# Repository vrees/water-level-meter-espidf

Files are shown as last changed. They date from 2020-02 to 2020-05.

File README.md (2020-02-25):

# water-level-meter
Measure the water level in Viktor's spring tank using ESP32 espidf Framework

### Links:
* Board: https://github.com/LilyGO/TTGO-LORA32
* https://github.com/manuelbl/ttn-esp32
* https://github.com/bertrik/LoraWanPmSensor/blob/master/Esp32PmSensor/Esp32PmSensor.ino
* Display Library u8g2: https://github.com/olikraus/u8g2/wiki

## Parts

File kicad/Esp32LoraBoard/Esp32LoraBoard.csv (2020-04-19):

Source | /home/vrees/work/git-repos/water-level-meter-espidf/kicad/Esp32LoraBoard/Esp32LoraBoard.sch
Kicad Rev | Eeschema 5.1.4-e60b266~84~ubuntu18.04.1
Generated Date | Sa 18 Apr 2020 08:45:09 CEST
Title | Esp32LoraBoard
Company | Viktor Rees
Revision | 1.1
Date Issue | 2020-04-11
Comment | Reset-Button added
Reference | Value | Feld4 | Feld5 | Feld6 | Feld7 | Description | Height | Manufacturer_Name | Manufacturer_Part_Number | Library | Library Ref
U3 | RFM95W-868S2 | RF_Module | RFM95W-868S2
J1 | USB_B_Micro | Connector | USB_B_Micro
C1 | 100n | Device | C
C2 | 10u | Device | CP_Small
R1 | 10k | Device | R
C4 | 100n | Device | C_Small
C3 | 1u | Device | C_Small
AE1 | Antenna_Shield | Device | Antenna_Shield
BT1 | LiFePo-Batterie | Device | Battery_Cell
U1 | LM3940IMP-3.3 | 41K5122 | LM3940IMP-33 | SOT-223-4 | National Semiconductors |  |  |  |  | LM3940IMP-3.3 | LM3940IMP-3.3
J2 | Power-Selector | Connector | Conn_01x03_Male
J4 | ESP_PROG_JTAG | Connector_Generic | Conn_02x05_Odd_Even
C5 | 1n | Device | C_Small
R2 | 10k | Device | R
C6 | 1n | Device | C_Small
Q1 | UMH3N |  |  |  |  | 2 NPN pre-biased (Dual) 100mA 50V SC-70-6(SOT-363) Digital Transistors RoHS | 1.1 | Changjiang Electronics Tech (CJ) | UMH3N | UMH3N | UMH3N
J5 | Prog | Connector | Conn_01x05_Male
U2 | ESP32-WROOM-32 | RF_Module | ESP32-WROOM-32
Q2 | Si2302DS_NMOS | Device | Q_NMOS_GSD
R5 | optional | Device | R
R6 | optional | Device | R
R7 | 100k | Device | R
J7 | Measurement-Selector | Connector | Conn_01x03_Male
R8 | 100k | Device | R
TP1 | TP_U_BATT | Connector | TestPoint
R4 | 10k | Device | R
R3 | 10k | Device | R
J6 | ext_Measure | Connector | Screw_Terminal_01x04
J3 | Testpoints | Connector | Conn_01x05_Male
Q3 | Si2301DS_PMOS | Device | Q_PMOS_GSD
TP3 | VCC_2 | Connector | TestPoint
Q5 | Si2301DS_PMOS | Device | Q_PMOS_GSD
R12 | 100k | Device | R
R13 | 10k | Device | R
R11 | 10k | Device | R
Q6 | Si2302DS_NMOS | Device | Q_NMOS_GSD
J8 | OLED_128x64 | Connector | Conn_01x04_Female
R10 | 10k | Device | R
R9 | 10k | Device | R
Q4 | Si2302DS_NMOS | Device | Q_NMOS_GSD
TP2 | TP_U_EXT | Connector | TestPoint
C8 | 100n | Device | C
C7 | 100n | Device | C
SW1 | Rotary_Encoder | Device | Rotary_Encoder_Switch
R14 | 10k | Device | R
R15 | 10k | Device | R
C9 | 1u | Device | C
C10 | 1u | Device | C
SW2 | Reset | Switch | SW_Push_Dual_x2

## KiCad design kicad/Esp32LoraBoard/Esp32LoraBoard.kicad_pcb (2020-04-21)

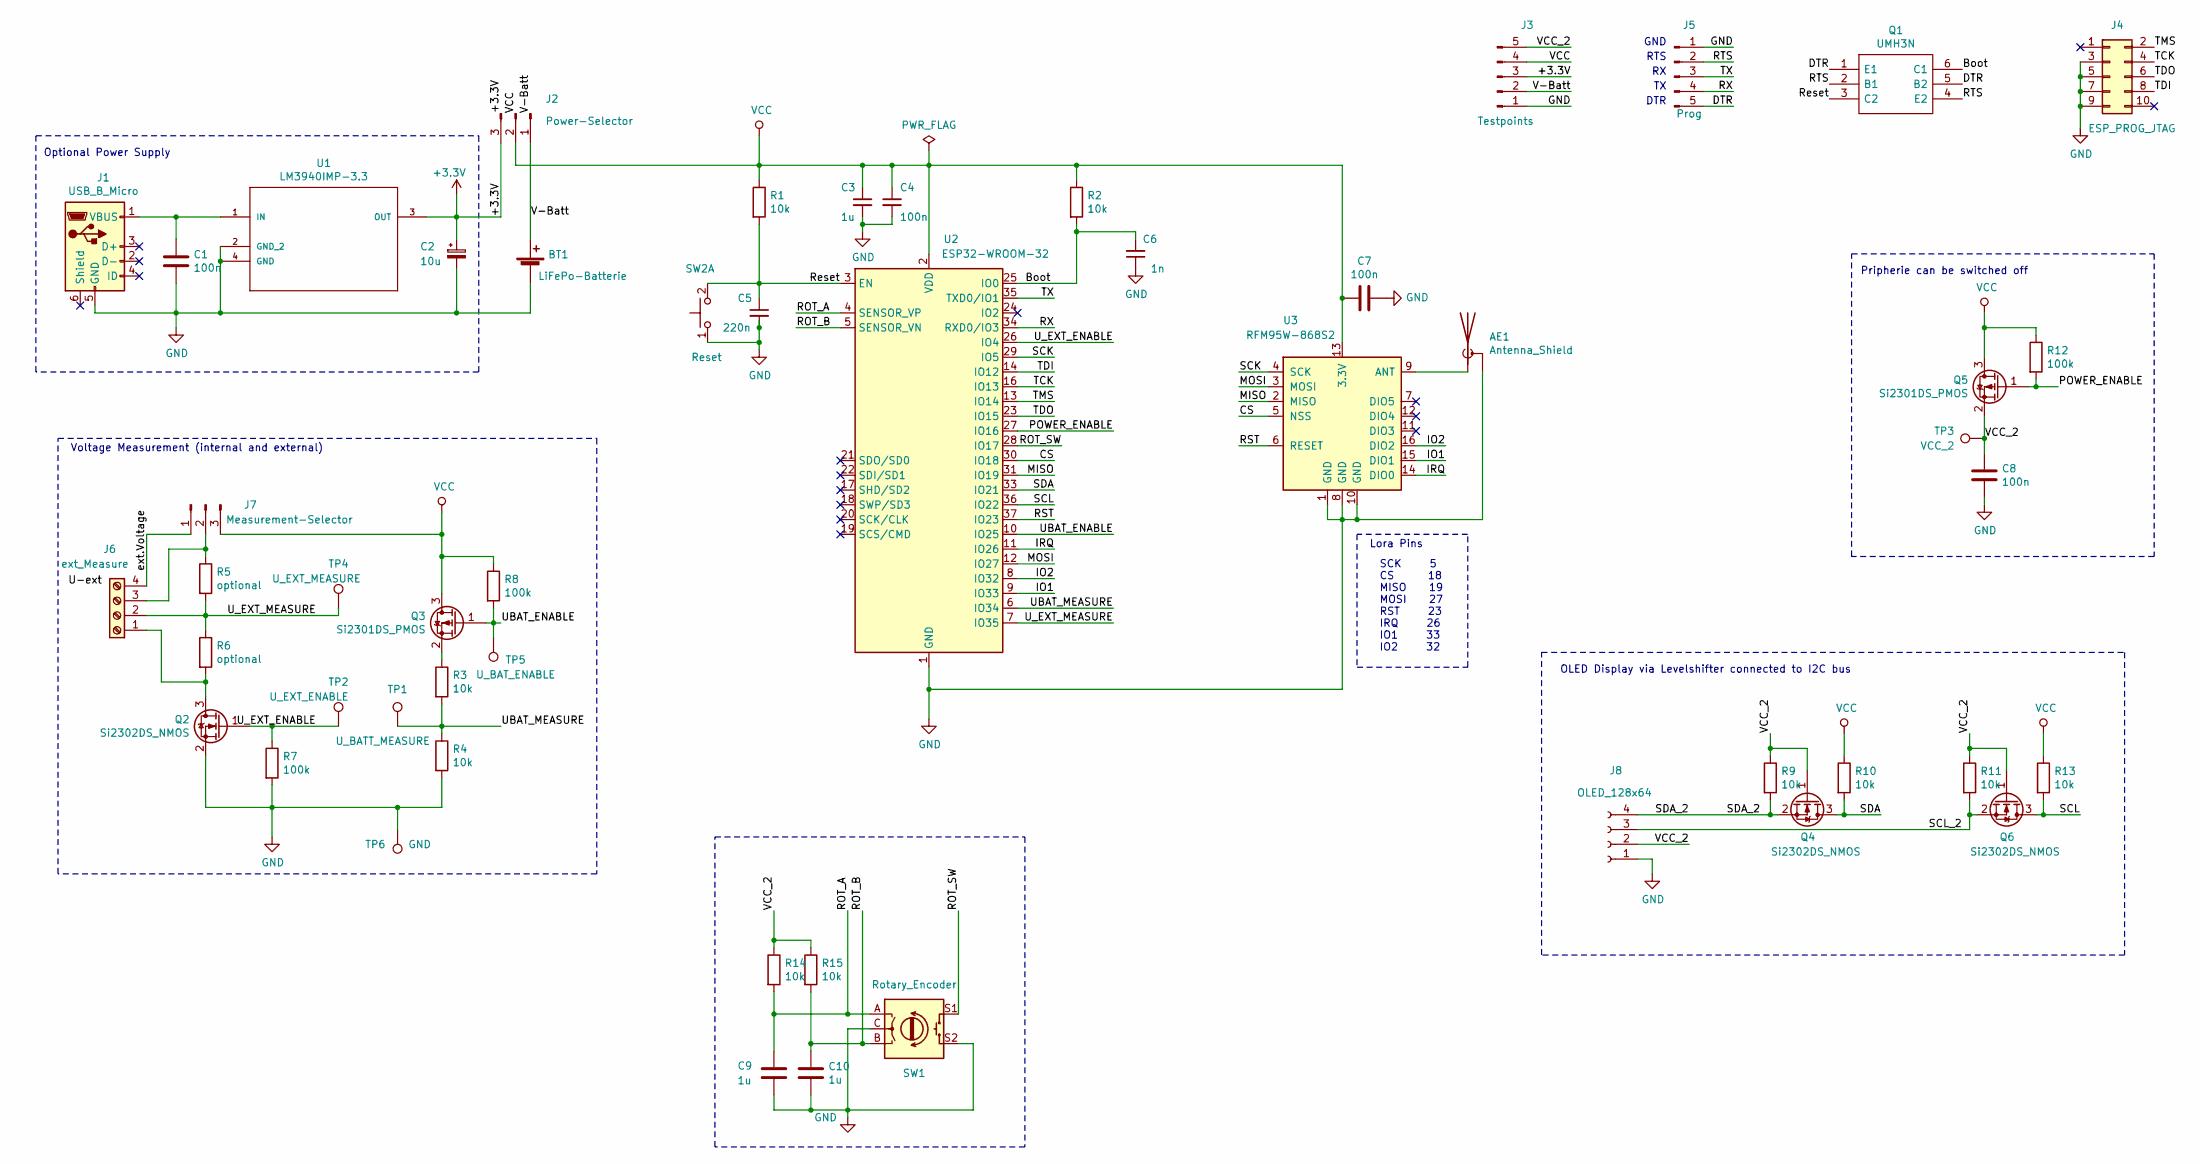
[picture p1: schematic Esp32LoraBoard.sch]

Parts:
AE1: Antenna_Shield; SMA_Samtec_SMA-J-P-H-ST-EM1_EdgeMount
BT1: LiFePo-Batterie; PhoenixContact_MSTBVA_2,5_2-G-5,08_1x02_P5.08mm_Vertical
C1, C4, C7, C8: 100n; C_1206_3216Metric_Pad1.42x1.75mm_HandSolder
C2: 10u; C_1206_3216Metric_Pad1.42x1.75mm_HandSolder
C3, C9, C10: 1u; C_1206_3216Metric_Pad1.42x1.75mm_HandSolder
C5: 220n; C_1206_3216Metric_Pad1.42x1.75mm_HandSolder
C6: 1n; C_1206_3216Metric_Pad1.42x1.75mm_HandSolder
J1: USB_B_Micro; USB_Micro-B_GCT_USB3076-30-A
J2: Power-Selector; PinHeader_1x03_P2.54mm_Vertical
J3: Testpoints; PinHeader_1x05_P2.54mm_Vertical
J4: ESP_PROG_JTAG; PinHeader_2x05_P1.27mm_Vertical
J5: Prog; PinHeader_1x05_P2.54mm_Vertical
J6: ext_Measure; PhoenixContact_MSTBVA_2,5_4-G-5,08_1x04_P5.08mm_Vertical
J7: Measurement-Selector; PinHeader_1x03_P2.54mm_Vertical
J8: OLED_128x64; PinHeader_1x04_P2.54mm_Vertical
Q1: UMH3N; SOT65P230X110-6N; Manufacturer_Part_Number UMH3N
Q2, Q4, Q6: Si2302DS_NMOS; TSOT-23_HandSoldering
Q3, Q5: Si2301DS_PMOS; TSOT-23_HandSoldering
R1, R2, R3, R4, R9, R10, R11, R13, R14, R15: 10k; R_1206_3216Metric_Pad1.42x1.75mm_HandSolder
R5, R6: optional; R_1206_3216Metric_Pad1.42x1.75mm_HandSolder
R7, R8, R12: 100k; R_1206_3216Metric_Pad1.42x1.75mm_HandSolder
SW1: Rotary_Encoder; RotaryEncoder_Alps_EC11E-Switch_Vertical_H20mm
SW2: Reset; SW_SPST_CK_RS282G05A3
TP1: U_BATT_MEASURE; PinHeader_1x01_P2.54mm_Vertical
TP2: U_EXT_ENABLE; PinHeader_1x01_P2.54mm_Vertical
TP3: VCC_2; PinHeader_1x01_P2.54mm_Vertical
TP4: U_EXT_MEASURE; PinHeader_1x01_P2.54mm_Vertical
TP5: U_BAT_ENABLE; PinHeader_1x01_P2.54mm_Vertical
TP6: GND; PinHeader_1x01_P2.54mm_Vertical
U1: LM3940IMP-3.3; SOT230P696X180-4N
U2: ESP32-WROOM-32
U3: RFM95W-868S2; HOPERF_RFM9XW_SMD

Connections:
+3V3: C2.1, J2.3, J3.3, U1.3 (OUT)
/Boot: C6.2, Q1.6 (C1), R2.2, U2.25 (IO0)
/CS: U2.30 (IO18), U3.5 (NSS)
/DTR: J5.5, Q1.1 (E1), Q1.5 (B2)
/IO1: U2.9 (IO33), U3.15 (DIO1)
/IO2: U2.8 (IO32), U3.16 (DIO2)
/IRQ: U2.11 (IO26), U3.14 (DIO0)
/MISO: U2.31 (IO19), U3.2 (MISO)
/MOSI: U2.12 (IO27), U3.3 (MOSI)
/POWER_ENABLE: Q5.1 (G), R12.2, U2.27 (IO16)
/ROT_A: C9.1, R14.2, SW1.A, U2.4 (SENSOR_VP)
/ROT_B: C10.1, R15.2, SW1.B, U2.5 (SENSOR_VN)
/ROT_SW: SW1.S1, U2.28 (IO17)
/RST: U2.37 (IO23), U3.6 (RESET)
/RTS: J5.2, Q1.2 (B1), Q1.4 (E2)
/RX: J5.4, U2.34 (RXD0/IO3)
/Reset: C5.1, Q1.3 (C2), R1.2, SW2.2 (D), U2.3 (EN)
/SCK: U2.29 (IO5), U3.4 (SCK)
/SCL: Q6.3 (D), R13.2, U2.36 (IO22)
/SCL_2: J8.3, Q6.2 (S), R11.2
/SDA: Q4.3 (D), R10.2, U2.33 (IO21)
/SDA_2: J8.4, Q4.2 (S), R9.2
/TCK: J4.4, U2.16 (IO13)
/TDI: J4.8, U2.14 (IO12)
/TDO: J4.6, U2.23 (IO15)
/TMS: J4.2, U2.13 (IO14)
/TX: J5.3, U2.35 (TXD0/IO1)
/UBAT_ENABLE: Q3.1 (G), R8.2, TP5.1, U2.10 (IO25)
/UBAT_MEASURE: R3.2, R4.1, TP1.1, U2.6 (IO34)
/U_EXT_ENABLE: Q2.1 (G), R7.1, TP2.1, U2.26 (IO4)
/U_EXT_MEASURE: J6.2, R5.2, R6.1, TP4.1, U2.7 (IO35)
/V-Batt: BT1.1 (+), J2.1, J3.2
/VCC_2: C8.1, J3.5, J8.2, Q4.1 (G), Q5.2 (S), Q6.1 (G), R9.1, R11.1, R14.1, R15.1, TP3.1
/ext.Voltage: J6.4, J7.1
GND: AE1.2 (Shield), BT1.2 (-), C1.2, C2.2, C3.2, C4.2, C5.2, C6.1, C7.1, C8.2, C9.2, C10.2, J1.5 (GND), J3.1, J4.3, J4.5, J4.7, J4.9, J5.1, J8.1, Q2.2 (S), R4.2, R7.2, SW1.C, SW1.S2, SW2.1 (C), TP6.1, U1.2 (GND_2), U1.4 (GND), U2.1 (GND), U2.15 (GND), U2.38 (GND), U3.1 (GND), U3.8 (GND), U3.10 (GND)
unnamed: AE1.1 (A), U3.9 (ANT)
unnamed: C1.1, J1.1 (VBUS), U1.1 (IN)
unnamed: J6.1, Q2.3 (D), R6.2
unnamed: J6.3, J7.2, R5.1
unnamed: Q3.2 (S), R3.1
VCC: C3.1, C4.1, C7.2, J2.2, J3.4, J7.3, Q3.3 (D), Q5.3 (D), R1.1, R2.1, R8.1, R10.1, R12.1, R13.1, U2.2 (VDD), U3.13 (3.3V)

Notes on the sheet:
SCK 5 CS 18 MISO 19 MOSI 27 RST 23 IRQ 26 IO1 33 IO2 32
DTR
RTS
GND
Lora Pins
OLED Display via Levelshifter connected to I2C bus
Pripherie can be switched off
Voltage Measurement (internal and external)
Optional Power Supply

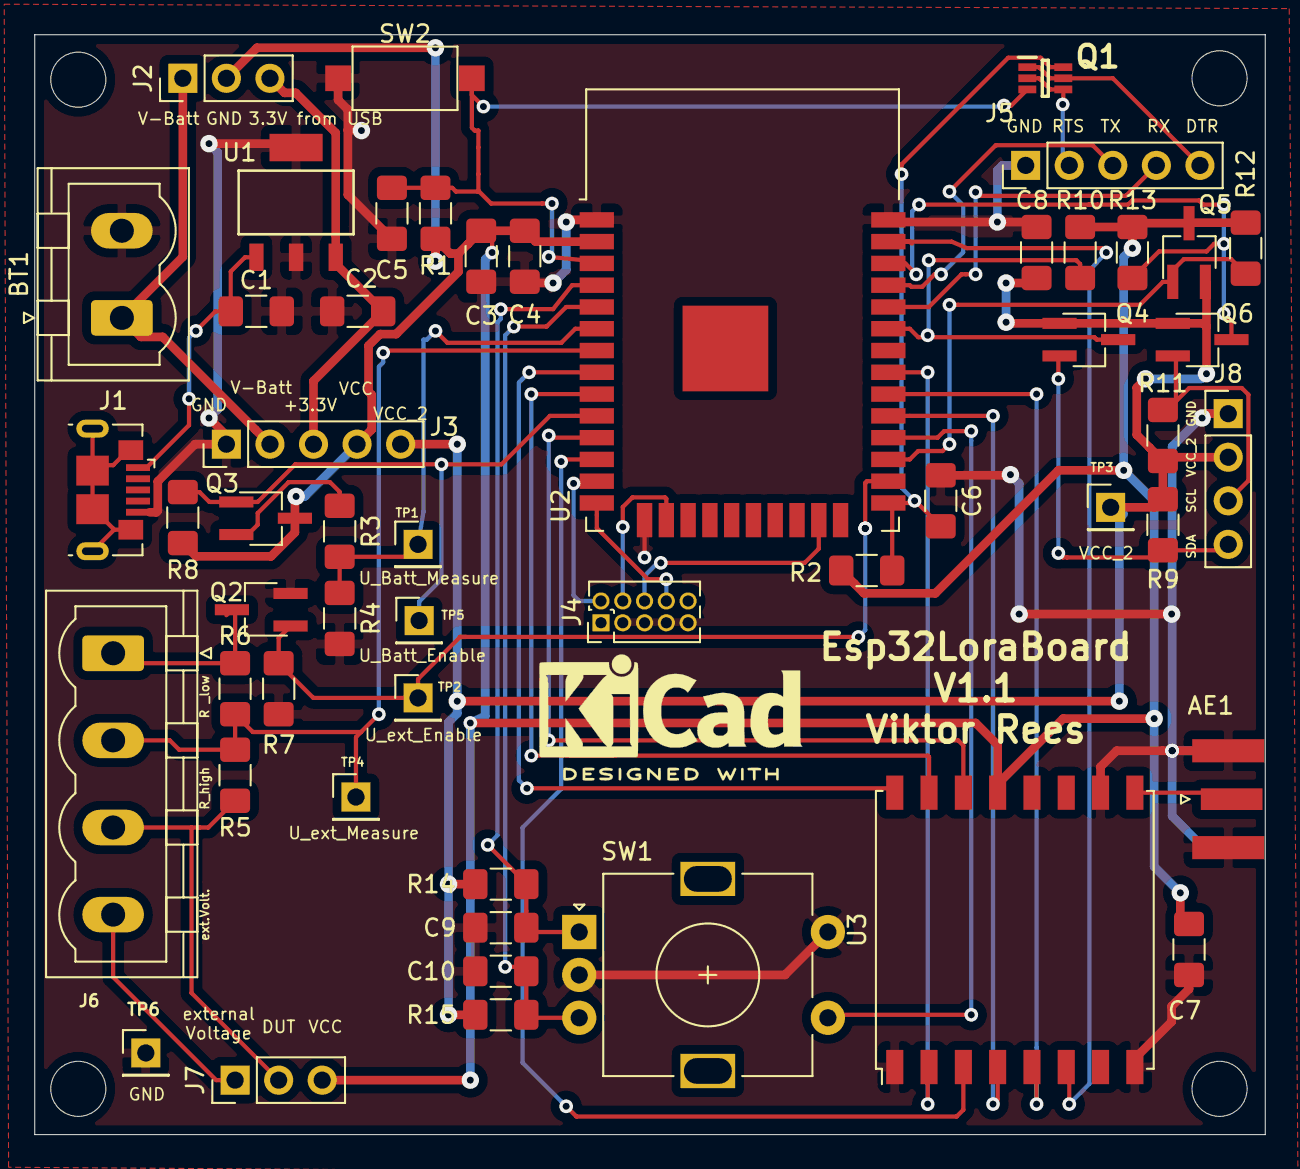
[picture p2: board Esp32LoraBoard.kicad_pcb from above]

Board: 2 copper layers, 71.8 x 64.1 mm, 52 parts (0 on the bottom side), 41 nets.

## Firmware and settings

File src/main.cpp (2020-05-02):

/*******************************************************************************
* eTapeContinuous Fluid Level Sensor PN-12110215TC-24  PN-6573TC-24
* Sensor Length: 660mm
* Active Sensor Length:12.4" 660mm
* Reference Resistor (Rref): 3000Ω, ±10%    gemessen:   3200Ω
* Sensor Output empty:       3000Ω          
* Sensor Output: full:        300Ω          gemessen:   400Ω
* Resistance Gradient: 44/cm, ±10%          
* PowerRating:  0.5 Watts (VMax = 10V)
*
* Voltage Gradient bei 3.3V:                gemessen:   48.7 V/cm
* s [cm] = 48.7cm/V * U[V] - 17.3cm         gerechnet:  46,5 V/cm
*
* https://github.com/LilyGO/TTGO-LORA32
* https://github.com/bertrik/LoraWanPmSensor/blob/master/Esp32PmSensor/Esp32PmSensor.ino
* https://github.com/manuelbl/ttn-esp32
*/

#include "freertos/FreeRTOS.h"
#include "esp_event.h"
#include "nvs_flash.h"
#include <stdio.h>
#include <string.h>
#include "esp_sleep.h"
#include "soc/rtc_cntl_reg.h"
#include "soc/sens_reg.h"
#include "driver/gpio.h"
#include "driver/rtc_io.h"
#include "driver/adc.h"
#include "driver/dac.h"
#include "esp32/ulp.h"
#include "ulp_main.h"
#include <Arduino.h>
#include "display.h"
#include "voltage.h"
#include "lora.h"

extern const uint8_t ulp_main_bin_start[] asm("_binary_ulp_main_bin_start");
extern const uint8_t ulp_main_bin_end[] asm("_binary_ulp_main_bin_end");

/* This function is called once after power-on reset, to load ULP program into
 * RTC memory and configure the ADC.
 */
static void init_ulp_program();

/* This function is called every time before going into deep sleep.
 * It starts the ULP program and resets measurement counter.
 */

const unsigned TX_INTERVAL = 5;

void arduinoTask(void *pvParameter)
{
    // pinMode(LED_RED, OUTPUT);
    while (1)
    {
        // digitalWrite(LED_RED, !digitalRead(LED_RED));
        delay(200);
    }
}

extern "C" void app_main(void)
{
    Serial.begin(115200);
    Serial.println("Start!");

    initArduino();
    initLora();
    initDisplay();
    initVoltage();
    readSensorValues();
    printValues();

    // xTaskCreate(&arduinoTask, "arduino_task", configMINIMAL_STACK_SIZE, NULL, 5, NULL);

    vTaskDelay(TX_INTERVAL * 1000 / portTICK_PERIOD_MS);
    printf("left app_main() program\n");
}

static void init_ulp_program()
{
    esp_err_t err = ulp_load_binary(0, ulp_main_bin_start,
                                    (ulp_main_bin_end - ulp_main_bin_start) / sizeof(uint32_t));
    ESP_ERROR_CHECK(err);

    /* Configure ADC channel */
    /* Note: when changing channel here, also change 'adc_channel' constant
       in adc.S */
    adc1_config_channel_atten(ADC1_CHANNEL_6, ADC_ATTEN_DB_11);
    adc1_config_width(ADC_WIDTH_BIT_12);
    adc1_ulp_enable();

    /* Set (low and high) thresholds, approx. 0.86V*/
    ulp_low_thr = 1;
    ulp_high_thr = 900;

    /* Set ULP wake up period to 20ms */
    ulp_set_wakeup_period(0, 2000000);

    /* Disconnect GPIO12 and GPIO15 to remove current drain through
     * pullup/pulldown resistors.
     * GPIO12 may be pulled high to select flash voltage.
     */
    rtc_gpio_isolate(GPIO_NUM_12);
    rtc_gpio_isolate(GPIO_NUM_15);
    esp_deep_sleep_disable_rom_logging(); // suppress boot messages
}

static void start_ulp_program()
{
    /* Reset sample counter */
    ulp_sample_counter = 0;

    /* Start the program */
    esp_err_t err = ulp_run(&ulp_entry - RTC_SLOW_MEM);
    ESP_ERROR_CHECK(err);
}

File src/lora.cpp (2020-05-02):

#include <Arduino.h>
#include "esp_event.h"
#include "nvs_flash.h"
#include <stdio.h>
#include <string.h>
// #include "esp_sleep.h"
// #include "soc/rtc_cntl_reg.h"
// #include "soc/sens_reg.h"
// #include "driver/gpio.h"
// #include "driver/rtc_io.h"

#include "TheThingsNetwork.h"
#include "voltage.h"

const char *devEui = "0013BB291B9FE7C5";
const char *appEui = "70B3D57ED0029C1F";
const char *appKey = "1D48B6FABE11BCC164028B0F0E9F4990";

// Pins and other resources
#define TTN_SPI_HOST HSPI_HOST
#define TTN_SPI_DMA_CHAN 1
#define TTN_PIN_SPI_SCLK 5
#define TTN_PIN_SPI_MOSI 27
#define TTN_PIN_SPI_MISO 19
#define TTN_PIN_NSS 18
#define TTN_PIN_RST 23
#define TTN_PIN_DIO0 26
#define TTN_PIN_DIO1 33
#define TTN_PIN_DIO2 32
#define TTN_PIN_RXTX TTN_NOT_CONNECTED

TheThingsNetwork ttn;


void sendMessages(void *pvParameter)
{

  printf("Sending message...\n");
  readSensorValues();
  // printValues();

  TTNResponseCode res = ttn.transmitMessage(lpp.getBuffer(), lpp.getSize());
  printf(res == kTTNSuccessfulTransmission ? "Message sent.\n" : "Transmission failed.\n");
}

void initLora()
{
  esp_err_t err;

  // Initialize the GPIO ISR handler service
  err = gpio_install_isr_service(ESP_INTR_FLAG_IRAM);
  ESP_ERROR_CHECK(err);

  // Initialize the NVS (non-volatile storage) for saving and restoring the keys
  err = nvs_flash_init();
  ESP_ERROR_CHECK(err);

  // Initialize SPI bus
  spi_bus_config_t spi_bus_config;
  spi_bus_config.miso_io_num = TTN_PIN_SPI_MISO;
  spi_bus_config.mosi_io_num = TTN_PIN_SPI_MOSI;
  spi_bus_config.sclk_io_num = TTN_PIN_SPI_SCLK;
  spi_bus_config.quadwp_io_num = -1;
  spi_bus_config.quadhd_io_num = -1;
  spi_bus_config.max_transfer_sz = 0;
  // spi_bus_config.intr_flags = spi_bus_config.intr_flags | !(ESP_INTR_FLAG_HIGH|ESP_INTR_FLAG_EDGE|ESP_INTR_FLAG_INTRDISABLED);
  err = spi_bus_initialize(TTN_SPI_HOST, &spi_bus_config, TTN_SPI_DMA_CHAN);
  ESP_ERROR_CHECK(err);

  // Configure the SX127x pins
  ttn.configurePins(TTN_SPI_HOST, TTN_PIN_NSS, TTN_PIN_RXTX, TTN_PIN_RST, TTN_PIN_DIO0, TTN_PIN_DIO1);

  // The below line can be commented after the first run as the data is saved in NVS
  ttn.provision(devEui, appEui, appKey);

  printf("Joining...\n");
  if (ttn.join())
  {
    printf("Joined.\n");
    // xTaskCreate(sendMessages, "send_messages", 2048 * 4, (void *)0, 3, nullptr);
    sendMessages(NULL);
  }
  else
  {
    printf("Join failed. Goodbye\n");
  }
}

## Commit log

2020-02-24 fixed spi problem
2020-02-24 display and voltage added
2020-02-24 still problem with display
    [display.cpp, main.cpp]
2020-02-25 adc.h added
2020-03-25 Diagram approved
    [Esp32LoraBoard.sch]
2020-03-29 schema version 1.0 done
    [Esp32LoraBoard.sch]
2020-04-11 Reset Button added
    [Esp32LoraBoard.kicad_pcb, Esp32LoraBoard.sch]
2020-04-19 Kicad Version V1.1
    [Esp32LoraBoard.csv, Esp32LoraBoard.sch]
2020-04-21 Reset Circuit modified. C5 = 100nF now in order to enter programming mode after reset
    [Esp32LoraBoard.kicad_pcb, Esp32LoraBoard.sch]
2020-04-21 exchanged RX/TX and Boot/Reset wires
    [Esp32LoraBoard.kicad_pcb, Esp32LoraBoard.sch]
